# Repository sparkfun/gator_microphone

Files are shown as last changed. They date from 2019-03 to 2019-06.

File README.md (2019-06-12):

SparkFun gator:microphone - micro:bit Accessory Board 
=============================

SparkFun gator:microphone - micro:bit Accessory Board

[*SparkFun gator:microphone - micro:bit Accessory Board (SEN-15289)*](https://www.sparkfun.com/products/15289)  

An I<sup>2</sup>C sensor for detecting sound with an electret microphone. The sensor measures the actual audio, amplitude envelope, and sound indication with an ADC (ADS1015).

Instead of using pin connections or requiring soldering, this product provides connection pads for a more kid freindly experience with alligator clips. The design intention of this product is to be used with the [gato:bit (v2)](https://www.sparkfun.com/products/15162), and the [micro:bit development board](https://www.sparkfun.com/products/14208).

Repository Contents
-------------------

* **/Hardware** - Eagle design files (.brd, .sch)
* **/Production** - Production panel files (.brd)

Documentation
--------------

* **[Hookup Guide](https://learn.sparkfun.com/tutorials/sparkfun-gatormicrophone-hookup-guide)** - Basic hookup guide for the gator:microphone.
* **[gator:microphone PXT Package](https://github.com/sparkfun/pxt-gator-microphone)** - PXT- package for the MakeCode gator:microphone extension.

License Information
-------------------

This product is _**open source**_! 

Please review the LICENSE.md file for license information. 

If you have any questions or concerns on licensing, please visit the [SparkFun Forum](https://forum.sparkfun.com/index.php) and post a topic. For more general questions related to our gator boards, please visit this section of the forum: [Gator Products](https://forum.sparkfun.com/viewforum.php?f=162).

Distributed as-is; no warranty is given.

- Your friends at SparkFun.

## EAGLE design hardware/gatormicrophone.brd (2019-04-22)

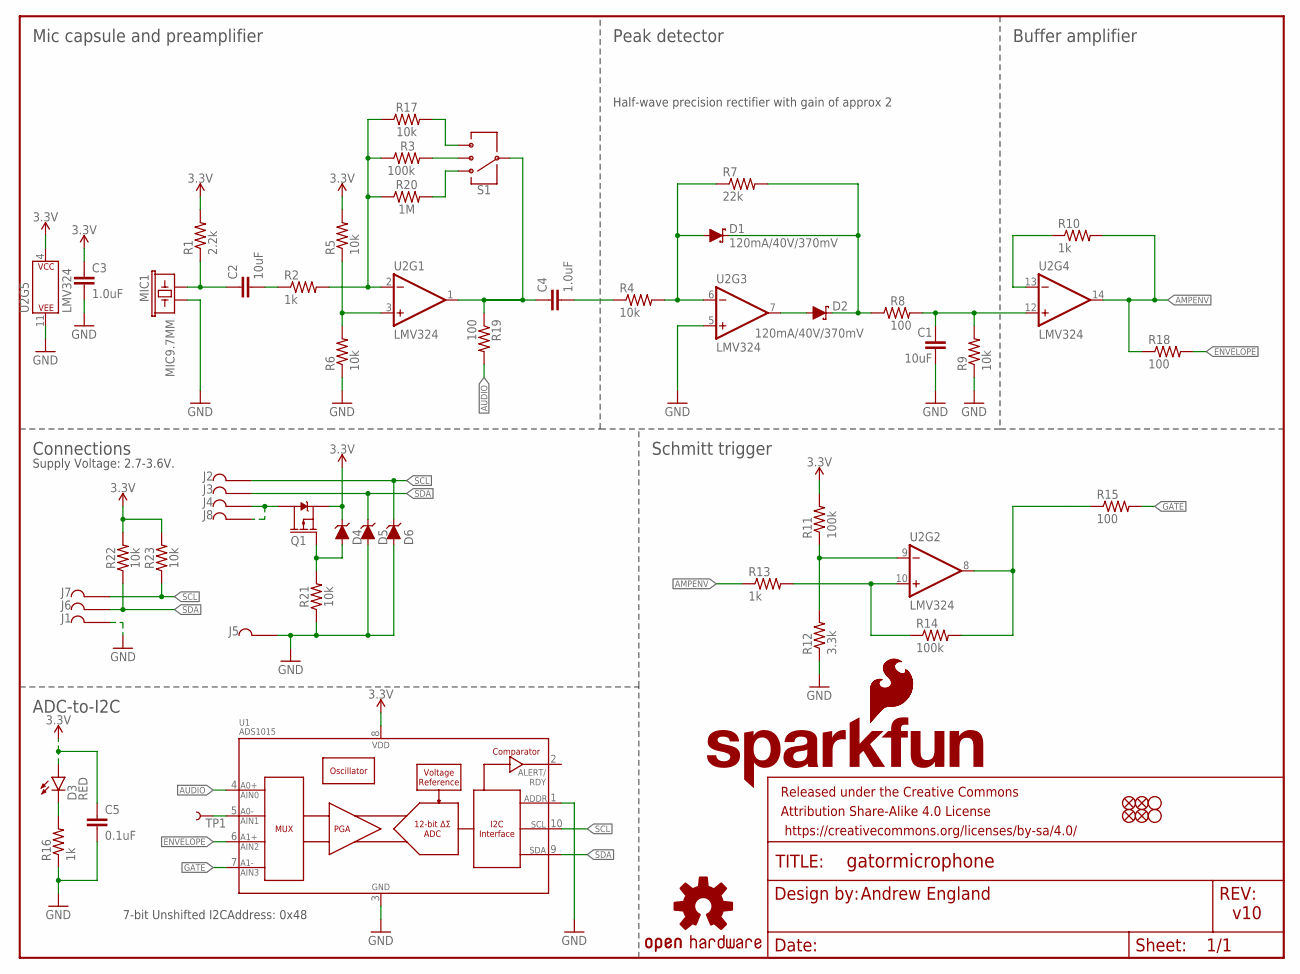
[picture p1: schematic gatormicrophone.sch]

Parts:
C1, C2: 10uF; 1206@1
C3, C4: 1.0uF; 0603
C5: 0.1uF; 0603
D1, D2: 120mA/40V/370mV; SOD-523
D3: RED; LED-0603
D4, D5, D6: 3.6V; SOD-323
FID1, FID2, FID3, FID4: FIDUCIAL1X2; FIDUCIAL-1X2
FRAME1: FRAME-LETTER; CREATIVE_COMMONS
H1, H2: STAND-OFFTIGHT; STAND-OFF-TIGHT
J1, J2, J3, J4, J5, J6, J7, J8: GATORGATOR_MINI; GATOR_MINI
LOGO1: OSHW-LOGOS; OSHW-LOGO-S
LOGO2: SFE_LOGO_NAME_FLAME.2_INCH; SFE_LOGO_NAME_FLAME_.2
LOGO3: SFE_LOGO_FLAME.2_INCH; SFE_LOGO_FLAME_.2
MIC1: MIC9.7MM; MIC-9.7MM
Q1: 2.5A/30V/105mΩ; SOT23-3
R1: 2.2k; 0603
R2, R10, R13, R16: 1k; 0603
R3, R11, R14: 100k; 0603
R4, R5, R6, R9, R17, R21, R22, R23: 10k; 0603
R7: 22k; 0603
R8, R15, R18, R19: 100; 0603
R12: 3.3k; 0603
R20: 1M; 0603
S1: SWITCH-SP3T-SMD; SWITCH_SP3T_SMD
TP1: TEST-POINT3; PAD.03X.03
U1: ADS1015; MSOP10
U2: LMV324; SO14

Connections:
3.3V: C3.1, C5.1, D3.A, D4.C, Q1.2 (S), R1.2, R5.2, R11.2, R22.2, R23.2, U1.8 (VDD), U2.4 (P$V+)
AMPENV: R10.2, R13.1, R18.1, U2.14 (OUT)
AUDIO: R19.2, U1.4 (AIN0)
ENVELOPE: R18.2, U1.6 (AIN2)
GATE: R15.2, U1.7 (AIN3)
GND: C1.2, C3.2, C5.2, D5.A, D6.A, J1.P$2, J5.P$2, MIC1.2, R6.1, R9.1, R12.1, R16.1, R21.1, U1.1 (ADDR), U1.3 (VSS), U2.5 (+IN), U2.11 (P$V-)
N$: C4.1, R19.1, S1.3, U2.1 (OUT)
unnamed: C2.1, MIC1.1, R1.1
unnamed: R5.1, R6.2, U2.3 (+IN)
unnamed: D3.C, R16.2
unnamed: R2.2, R3.1, R17.1, R20.1, U2.2 (-IN)
unnamed: C2.2, R2.1
unnamed: C4.2, R4.1
unnamed: D1.A, R4.2, R7.1, U2.6 (-IN)
unnamed: D2.A, U2.7 (OUT)
unnamed: D1.C, D2.C, R7.2, R8.1
unnamed: C1.1, R8.2, R9.2, U2.12 (+IN)
unnamed: R10.1, U2.13 (-IN)
unnamed: TP1.P$1, U1.5 (AIN1)
unnamed: R17.2, S1.4
unnamed: R3.2, S1.2
unnamed: R11.1, R12.2, U2.9 (-IN)
unnamed: R13.2, R14.1, U2.10 (+IN)
unnamed: R14.2, R15.1, U2.8 (OUT)
unnamed: R20.2, S1.1
unnamed: J4.P$2, J8.P$2, Q1.3 (D)
unnamed: D4.A, Q1.1 (G), R21.2
SCL: D6.C, J2.P$2, J7.P$2, R23.1, U1.10 (SCL)
SDA: D5.C, J3.P$2, J6.P$2, R22.1, U1.9 (SDA)

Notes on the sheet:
Andrew England
v10
Mic capsule and preamplifier
Peak detector
Buffer amplifier
Connections
Schmitt trigger
Half-wave precision rectifier with gain of approx 2
Supply Voltage: 2.7-3.6V.
ADC-to-I2C
7-bit Unshifted I2CAddress: 0x48

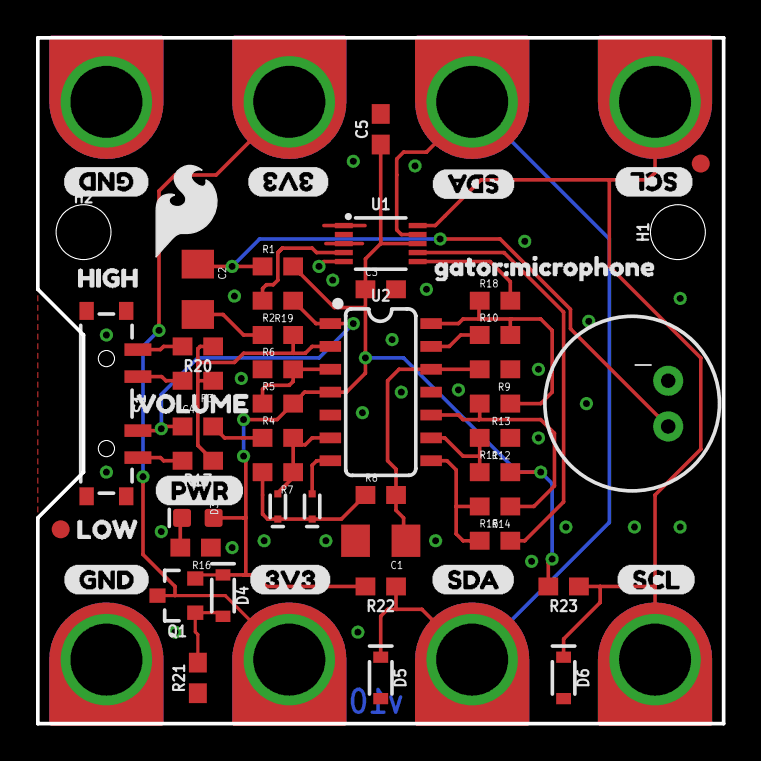
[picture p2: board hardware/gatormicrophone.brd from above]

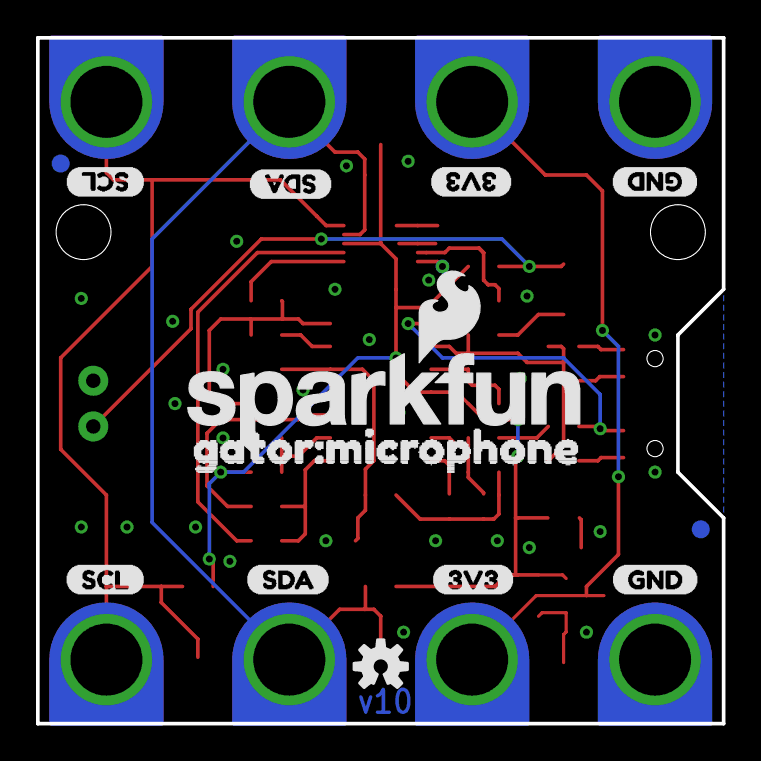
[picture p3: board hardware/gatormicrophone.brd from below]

Board: 2 copper layers, 38.1 x 38.1 mm, 81 parts (14 on the bottom side), 29 nets.

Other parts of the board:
U$1, U$7, U$11, U$18: 3V31
U$2, U$9, U$13, U$20: SCL1
U$3, U$8, U$12, U$19: SDA2
U$4: PWR0
U$5, U$6, U$10, U$17: GND0
U$14: GATOR#MICROPHONE1
U$15: LOW1
U$16: VOLUME2
U$21: HIGH0
U$22: ORDERING_INSTRUCTIONS
U$24: GATOR#MICROPHONE0

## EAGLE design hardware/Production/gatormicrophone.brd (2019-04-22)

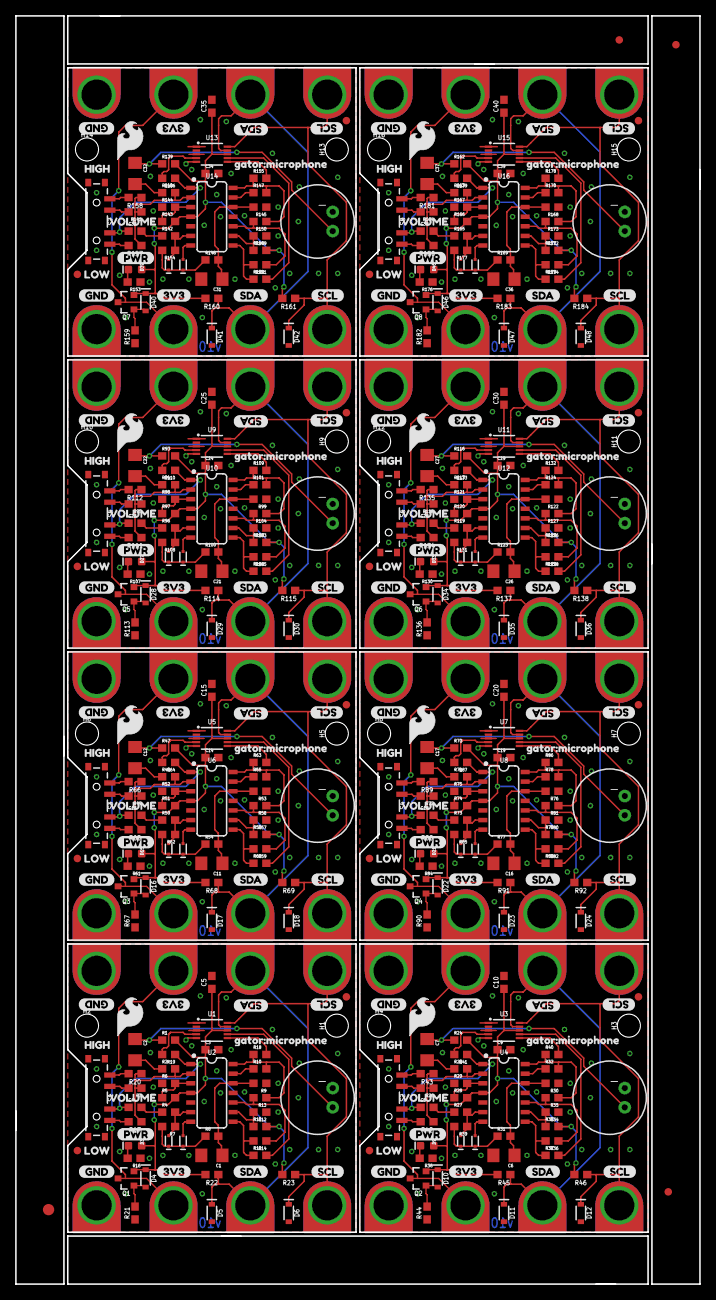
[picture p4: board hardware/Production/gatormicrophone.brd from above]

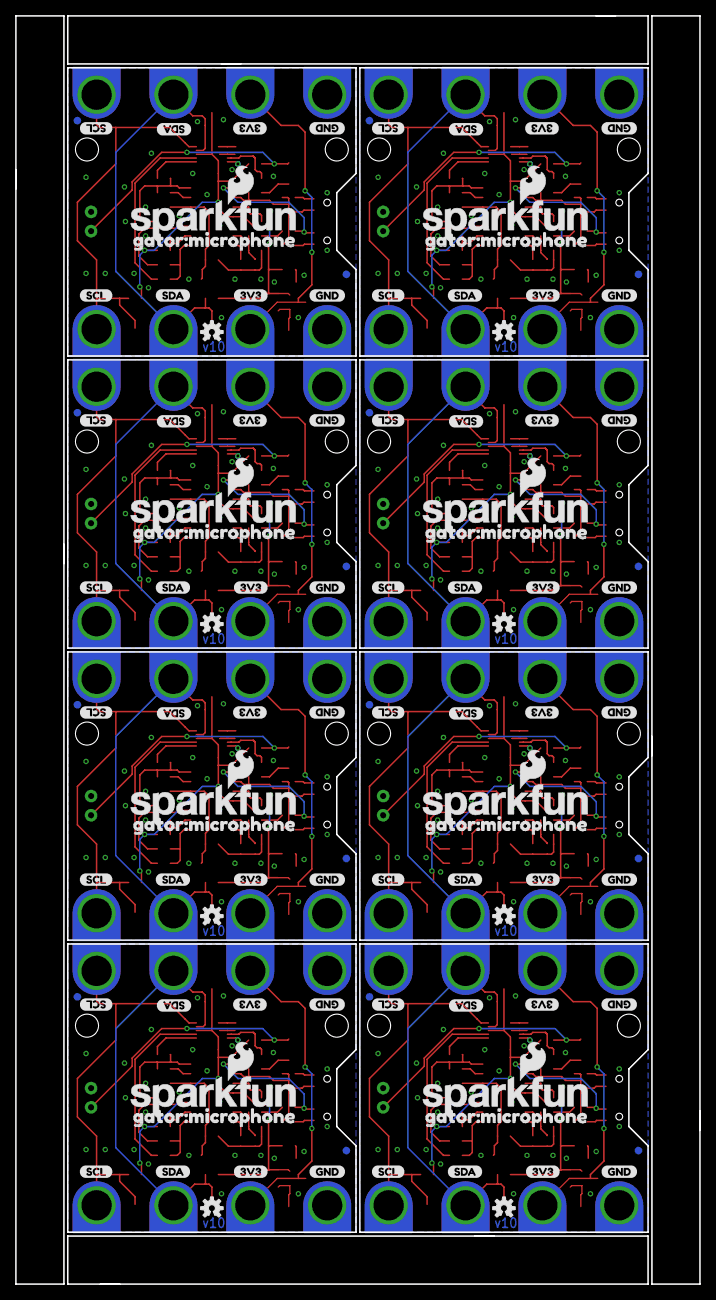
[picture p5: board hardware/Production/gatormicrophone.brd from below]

Board: 2 copper layers, 90.4 x 167.6 mm, 639 parts (112 on the bottom side), 232 nets.

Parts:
C1, C2, C6, C7, C11, C12, C16, C17, C21, C22, C26, C27, C31, C32, C36, C37: 10uF; 1206@1
C3, C4, C8, C9, C13, C14, C18, C19, C23, C24, C28, C29, C33, C34, C38, C39: 1.0uF; 0603
C5, C10, C15, C20, C25, C30, C35, C40: 0.1uF; 0603
D1, D2, D7, D8, D13, D14, D19, D20, D25, D26, D31, D32, D37, D38, D43, D44: 120mA/40V/370mV; SOD-523
D3, D9, D15, D21, D27, D33, D39, D45: RED; LED-0603
D4, D5, D6, D10, D11, D12, D16, D17, D18, D22, D23, D24, D28, D29, D30, D34, D35, D36, D40, D41, D42, D46, D47, D48: 3.6V; SOD-323
E$3: FIDUCIAL-1.5X3
E$5, E$7, E$8: FIDUCIAL-1X2
FID1, FID2, FID3, FID4, FID5, FID6, FID7, FID8, FID9, FID10, FID11, FID12, FID13, FID14, FID15, FID16, FID17, FID18, FID19, FID20, FID21, FID22, FID23, FID24, FID25, FID26, FID27, FID28, FID29, FID30, FID31, FID32: FIDUCIAL1X2; FIDUCIAL-1X2
FRAME1, FRAME2: FRAME-LETTER; CREATIVE_COMMONS
H1, H2, H3, H4, H5, H6, H7, H8, H9, H10, H11, H12, H13, H14, H15, H16: STAND-OFFTIGHT; STAND-OFF-TIGHT
J1, J2, J3, J4, J5, J6, J7, J8, J9, J10, J11, J12, J13, J14, J15, J16, J17, J18, J19, J20, J21, J22, J23, J24, J25, J26, J27, J28, J29, J30, J31, J32, J33, J34, J35, J36, J37, J38, J39, J40, J41, J42, J43, J44, J45, J46, J47, J48, J49, J50, J51, J52, J53, J54, J55, J56, J57, J58, J59, J60, J61, J62, J63, J64: GATORGATOR_MINI; GATOR_MINI
LOGO1, LOGO4, LOGO7, LOGO10, LOGO13, LOGO16, LOGO19, LOGO22: OSHW-LOGOS; OSHW-LOGO-S
LOGO2, LOGO5, LOGO8, LOGO11, LOGO14, LOGO17, LOGO20, LOGO23: SFE_LOGO_NAME_FLAME.2_INCH; SFE_LOGO_NAME_FLAME_.2
LOGO3, LOGO6, LOGO9, LOGO12, LOGO15, LOGO18, LOGO21, LOGO24: SFE_LOGO_FLAME.2_INCH; SFE_LOGO_FLAME_.2
MIC1, MIC2, MIC3, MIC4, MIC5, MIC6, MIC7, MIC8: MIC9.7MM; MIC-9.7MM
Q1, Q2, Q3, Q4, Q5, Q6, Q7, Q8: 2.5A/30V/105mΩ; SOT23-3
R1, R24, R47, R70, R93, R116, R139, R162: 2.2k; 0603
R2, R10, R13, R16, R25, R32, R35, R38, R48, R55, R58, R61, R71, R78, R81, R84, R94, R101, R104, R107, R117, R124, R127, R130, R140, R147, R150, R153, R163, R170, R173, R176: 1k; 0603
R3, R11, R14, R26, R33, R36, R49, R56, R59, R72, R79, R82, R95, R102, R105, R118, R125, R128, R141, R148, R151, R164, R171, R174: 100k; 0603
R4, R5, R6, R9, R17, R21, R22, R23, R27, R28, R29, R30, R42, R44, R45, R46, R50, R51, R52, R53, R65, R67, R68, R69, R73, R74, R75, R76, R88, R90, R91, R92, R96, R97, R98, R99, R111, R113, R114, R115, R119, R120, R121, R122, R134, R136, R137, R138, R142, R143, R144, R145, R157, R159, R160, R161, R165, R166, R167, R168, R180, R182, R183, R184: 10k; 0603
R7, R39, R62, R85, R108, R131, R154, R177: 22k; 0603
R8, R15, R18, R19, R31, R37, R40, R41, R54, R60, R63, R64, R77, R83, R86, R87, R100, R106, R109, R110, R123, R129, R132, R133, R146, R152, R155, R156, R169, R175, R178, R179: 100; 0603
R12, R34, R57, R80, R103, R126, R149, R172: 3.3k; 0603
R20, R43, R66, R89, R112, R135, R158, R181: 1M; 0603
S1, S2, S3, S4, S5, S6, S7, S8: SWITCH_SP3T_SMD
TP1, TP2, TP3, TP4, TP5, TP6, TP7, TP8: TEST-POINT3; PAD.03X.03
U1, U3, U5, U7, U9, U11, U13, U15: ADS1015; MSOP10
U2, U4, U6, U8, U10, U12, U14, U16: LMV324; SO14
U$1, U$7, U$11, U$18, U$23, U$27, U$34, U$40, U$46, U$49, U$56, U$62, U$68, U$71, U$78, U$84, U$90, U$93, U$100, U$106, U$112, U$115, U$122, U$128, U$134, U$137, U$144, U$150, U$156, U$159, U$166, U$172: 3V31
U$2, U$9, U$13, U$20, U$28, U$32, U$36, U$42, U$50, U$54, U$58, U$64, U$72, U$76, U$80, U$86, U$94, U$98, U$102, U$108, U$116, U$120, U$124, U$130, U$138, U$142, U$146, U$152, U$160, U$164, U$168, U$174: SCL1
U$3, U$8, U$12, U$19, U$29, U$31, U$35, U$41, U$51, U$53, U$57, U$63, U$73, U$75, U$79, U$85, U$95, U$97, U$101, U$107, U$117, U$119, U$123, U$129, U$139, U$141, U$145, U$151, U$161, U$163, U$167, U$173: SDA2
U$4, U$30, U$52, U$74, U$96, U$118, U$140, U$162: PWR0
U$5, U$6, U$10, U$17, U$25, U$26, U$33, U$39, U$47, U$48, U$55, U$61, U$69, U$70, U$77, U$83, U$91, U$92, U$99, U$105, U$113, U$114, U$121, U$127, U$135, U$136, U$143, U$149, U$157, U$158, U$165, U$171: GND0
U$14, U$45, U$67, U$89, U$111, U$133, U$155, U$177: GATOR#MICROPHONE1
U$15, U$37, U$59, U$81, U$103, U$125, U$147, U$169: LOW1
U$16, U$38, U$60, U$82, U$104, U$126, U$148, U$170: VOLUME2
U$21, U$43, U$65, U$87, U$109, U$131, U$153, U$175: HIGH0
U$22: ORDERING_INSTRUCTIONS
U$24, U$44, U$66, U$88, U$110, U$132, U$154, U$176: GATOR#MICROPHONE0

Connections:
3.3V: C3.1, C5.1, D3.A, D4.C, Q1.2, R1.2, R5.2, R11.2, R22.2, R23.2, U1.8, U2.4
3.3V1: C9.1, C10.1, D9.A, D10.C, Q2.2, R24.2, R28.2, R33.2, R45.2, R46.2, U3.8, U4.4
3.3V2: C14.1, C15.1, D15.A, D16.C, Q3.2, R47.2, R51.2, R56.2, R68.2, R69.2, U5.8, U6.4
3.3V3: C19.1, C20.1, D21.A, D22.C, Q4.2, R70.2, R74.2, R79.2, R91.2, R92.2, U7.8, U8.4
3.3V4: C24.1, C25.1, D27.A, D28.C, Q5.2, R93.2, R97.2, R102.2, R114.2, R115.2, U9.8, U10.4
3.3V5: C29.1, C30.1, D33.A, D34.C, Q6.2, R116.2, R120.2, R125.2, R137.2, R138.2, U11.8, U12.4
3.3V6: C34.1, C35.1, D39.A, D40.C, Q7.2, R139.2, R143.2, R148.2, R160.2, R161.2, U13.8, U14.4
3.3V7: C39.1, C40.1, D45.A, D46.C, Q8.2, R162.2, R166.2, R171.2, R183.2, R184.2, U15.8, U16.4
AMPENV: R10.2, R13.1, R18.1, U2.14
AMPENV1: R32.2, R35.1, R40.1, U4.14
AMPENV2: R55.2, R58.1, R63.1, U6.14
AMPENV3: R78.2, R81.1, R86.1, U8.14
AMPENV4: R101.2, R104.1, R109.1, U10.14
AMPENV5: R124.2, R127.1, R132.1, U12.14
AMPENV6: R147.2, R150.1, R155.1, U14.14
AMPENV7: R170.2, R173.1, R178.1, U16.14
AUDIO: R19.2, U1.4
AUDIO1: R41.2, U3.4
AUDIO2: R64.2, U5.4
AUDIO3: R87.2, U7.4
AUDIO4: R110.2, U9.4
AUDIO5: R133.2, U11.4
AUDIO6: R156.2, U13.4
AUDIO7: R179.2, U15.4
ENVELOPE: R18.2, U1.6
ENVELOPE1: R40.2, U3.6
ENVELOPE2: R63.2, U5.6
ENVELOPE3: R86.2, U7.6
ENVELOPE4: R109.2, U9.6
ENVELOPE5: R132.2, U11.6
ENVELOPE6: R155.2, U13.6
ENVELOPE7: R178.2, U15.6
GATE: R15.2, U1.7
GATE1: R37.2, U3.7
GATE2: R60.2, U5.7
GATE3: R83.2, U7.7
GATE4: R106.2, U9.7
GATE5: R129.2, U11.7
GATE6: R152.2, U13.7
GATE7: R175.2, U15.7
GND: C1.2, C3.2, C5.2, D5.A, D6.A, J1.P$2, J5.P$2, MIC1.2, R6.1, R9.1, R12.1, R16.1, R21.1, U1.1, U1.3, U2.5, U2.11
GND1: C6.2, C9.2, C10.2, D11.A, D12.A, J12.P$2, J13.P$2, MIC2.2, R29.1, R30.1, R34.1, R38.1, R44.1, U3.1, U3.3, U4.5, U4.11
GND2: C11.2, C14.2, C15.2, D17.A, D18.A, J20.P$2, J21.P$2, MIC3.2, R52.1, R53.1, R57.1, R61.1, R67.1, U5.1, U5.3, U6.5, U6.11
GND3: C16.2, C19.2, C20.2, D23.A, D24.A, J28.P$2, J29.P$2, MIC4.2, R75.1, R76.1, R80.1, R84.1, R90.1, U7.1, U7.3, U8.5, U8.11
GND4: C21.2, C24.2, C25.2, D29.A, D30.A, J36.P$2, J37.P$2, MIC5.2, R98.1, R99.1, R103.1, R107.1, R113.1, U9.1, U9.3, U10.5, U10.11
GND5: C26.2, C29.2, C30.2, D35.A, D36.A, J44.P$2, J45.P$2, MIC6.2, R121.1, R122.1, R126.1, R130.1, R136.1, U11.1, U11.3, U12.5, U12.11
GND6: C31.2, C34.2, C35.2, D41.A, D42.A, J52.P$2, J53.P$2, MIC7.2, R144.1, R145.1, R149.1, R153.1, R159.1, U13.1, U13.3, U14.5, U14.11
GND7: C36.2, C39.2, C40.2, D47.A, D48.A, J60.P$2, J61.P$2, MIC8.2, R167.1, R168.1, R172.1, R176.1, R182.1, U15.1, U15.3, U16.5, U16.11
N$: C4.1, R19.1, S1.3, U2.1
unnamed: C2.1, MIC1.1, R1.1
unnamed: R5.1, R6.2, U2.3
unnamed: D3.C, R16.2
unnamed: R2.2, R3.1, R17.1, R20.1, U2.2
unnamed: C2.2, R2.1
unnamed: C4.2, R4.1
unnamed: D1.A, R4.2, R7.1, U2.6
unnamed: D2.A, U2.7
unnamed: D1.C, D2.C, R7.2, R8.1
unnamed: C1.1, R8.2, R9.2, U2.12
unnamed: R10.1, U2.13
unnamed: TP1.P$1, U1.5
unnamed: R17.2, S1.4
unnamed: R3.2, S1.2
unnamed: R11.1, R12.2, U2.9
unnamed: R13.2, R14.1, U2.10
unnamed: R14.2, R15.1, U2.8
unnamed: R20.2, S1.1
unnamed: J4.P$2, J8.P$2, Q1.3
unnamed: D4.A, Q1.1, R21.2
unnamed: C7.1, MIC2.1, R24.1
unnamed: R28.1, R29.2, U4.3
unnamed: R25.2, R26.1, R42.1, R43.1, U4.2
unnamed: C7.2, R25.1
unnamed: C8.2, R27.1
unnamed: D7.A, R27.2, R39.1, U4.6
unnamed: D8.A, U4.7
unnamed: D7.C, D8.C, R31.1, R39.2
unnamed: C6.1, R30.2, R31.2, U4.12
unnamed: R32.1, U4.13
unnamed: R33.1, R34.2, U4.9
unnamed: R35.2, R36.1, U4.10
unnamed: R36.2, R37.1, U4.8
unnamed: D9.C, R38.2
unnamed: C8.1, R41.1, S2.3, U4.1
unnamed: R42.2, S2.4
unnamed: R26.2, S2.2
unnamed: R43.2, S2.1
unnamed: J11.P$2, J16.P$2, Q2.3
unnamed: D10.A, Q2.1, R44.2
unnamed: TP2.P$1, U3.5
unnamed: C12.1, MIC3.1, R47.1
unnamed: R51.1, R52.2, U6.3
unnamed: R48.2, R49.1, R65.1, R66.1, U6.2
unnamed: C12.2, R48.1
unnamed: C13.2, R50.1
unnamed: D13.A, R50.2, R62.1, U6.6
unnamed: D14.A, U6.7
unnamed: D13.C, D14.C, R54.1, R62.2
unnamed: C11.1, R53.2, R54.2, U6.12
unnamed: R55.1, U6.13
unnamed: R56.1, R57.2, U6.9
unnamed: R58.2, R59.1, U6.10
unnamed: R59.2, R60.1, U6.8
unnamed: D15.C, R61.2
unnamed: C13.1, R64.1, S3.3, U6.1
unnamed: R65.2, S3.4
unnamed: R49.2, S3.2
unnamed: R66.2, S3.1
unnamed: J19.P$2, J24.P$2, Q3.3
unnamed: D16.A, Q3.1, R67.2
unnamed: TP3.P$1, U5.5
unnamed: C17.1, MIC4.1, R70.1
unnamed: R74.1, R75.2, U8.3
unnamed: R71.2, R72.1, R88.1, R89.1, U8.2
unnamed: C17.2, R71.1
unnamed: C18.2, R73.1
unnamed: D19.A, R73.2, R85.1, U8.6
unnamed: D20.A, U8.7
unnamed: D19.C, D20.C, R77.1, R85.2
unnamed: C16.1, R76.2, R77.2, U8.12
unnamed: R78.1, U8.13
unnamed: R79.1, R80.2, U8.9
unnamed: R81.2, R82.1, U8.10
unnamed: R82.2, R83.1, U8.8
unnamed: D21.C, R84.2
unnamed: C18.1, R87.1, S4.3, U8.1
unnamed: R88.2, S4.4
unnamed: R72.2, S4.2
unnamed: R89.2, S4.1
unnamed: J27.P$2, J32.P$2, Q4.3
unnamed: D22.A, Q4.1, R90.2
unnamed: TP4.P$1, U7.5
unnamed: C22.1, MIC5.1, R93.1
unnamed: R97.1, R98.2, U10.3
unnamed: R94.2, R95.1, R111.1, R112.1, U10.2
unnamed: C22.2, R94.1
unnamed: C23.2, R96.1
unnamed: D25.A, R96.2, R108.1, U10.6
unnamed: D26.A, U10.7
unnamed: D25.C, D26.C, R100.1, R108.2
unnamed: C21.1, R99.2, R100.2, U10.12
unnamed: R101.1, U10.13
unnamed: R102.1, R103.2, U10.9
unnamed: R104.2, R105.1, U10.10
unnamed: R105.2, R106.1, U10.8
unnamed: D27.C, R107.2
unnamed: C23.1, R110.1, S5.3, U10.1
unnamed: R111.2, S5.4
unnamed: R95.2, S5.2
unnamed: R112.2, S5.1
unnamed: J35.P$2, J40.P$2, Q5.3
unnamed: D28.A, Q5.1, R113.2
unnamed: TP5.P$1, U9.5
unnamed: C27.1, MIC6.1, R116.1
unnamed: R120.1, R121.2, U12.3
unnamed: R117.2, R118.1, R134.1, R135.1, U12.2
unnamed: C27.2, R117.1
unnamed: C28.2, R119.1
unnamed: D31.A, R119.2, R131.1, U12.6
unnamed: D32.A, U12.7
unnamed: D31.C, D32.C, R123.1, R131.2
unnamed: C26.1, R122.2, R123.2, U12.12
unnamed: R124.1, U12.13
unnamed: R125.1, R126.2, U12.9
unnamed: R127.2, R128.1, U12.10
unnamed: R128.2, R129.1, U12.8
unnamed: D33.C, R130.2
unnamed: C28.1, R133.1, S6.3, U12.1
unnamed: R134.2, S6.4
unnamed: R118.2, S6.2
unnamed: R135.2, S6.1
unnamed: J43.P$2, J48.P$2, Q6.3
unnamed: D34.A, Q6.1, R136.2
unnamed: TP6.P$1, U11.5
unnamed: C32.1, MIC7.1, R139.1
unnamed: R143.1, R144.2, U14.3
unnamed: R140.2, R141.1, R157.1, R158.1, U14.2
unnamed: C32.2, R140.1
unnamed: C33.2, R142.1
unnamed: D37.A, R142.2, R154.1, U14.6
unnamed: D38.A, U14.7
unnamed: D37.C, D38.C, R146.1, R154.2
unnamed: C31.1, R145.2, R146.2, U14.12
unnamed: R147.1, U14.13
unnamed: R148.1, R149.2, U14.9
unnamed: R150.2, R151.1, U14.10
unnamed: R151.2, R152.1, U14.8
unnamed: D39.C, R153.2
unnamed: C33.1, R156.1, S7.3, U14.1
unnamed: R157.2, S7.4
unnamed: R141.2, S7.2
unnamed: R158.2, S7.1
unnamed: J51.P$2, J56.P$2, Q7.3
unnamed: D40.A, Q7.1, R159.2
unnamed: TP7.P$1, U13.5
unnamed: C37.1, MIC8.1, R162.1
unnamed: R166.1, R167.2, U16.3
unnamed: R163.2, R164.1, R180.1, R181.1, U16.2
unnamed: C37.2, R163.1
unnamed: C38.2, R165.1
unnamed: D43.A, R165.2, R177.1, U16.6
unnamed: D44.A, U16.7
unnamed: D43.C, D44.C, R169.1, R177.2
unnamed: C36.1, R168.2, R169.2, U16.12
unnamed: R170.1, U16.13
unnamed: R171.1, R172.2, U16.9
unnamed: R173.2, R174.1, U16.10
unnamed: R174.2, R175.1, U16.8
unnamed: D45.C, R176.2
unnamed: C38.1, R179.1, S8.3, U16.1
unnamed: R180.2, S8.4
unnamed: R164.2, S8.2
unnamed: R181.2, S8.1
unnamed: J59.P$2, J64.P$2, Q8.3
unnamed: D46.A, Q8.1, R182.2
unnamed: TP8.P$1, U15.5
SCL: D6.C, J2.P$2, J7.P$2, R23.1, U1.10
SCL1: D12.C, J9.P$2, J15.P$2, R46.1, U3.10
SCL2: D18.C, J17.P$2, J23.P$2, R69.1, U5.10
SCL3: D24.C, J25.P$2, J31.P$2, R92.1, U7.10
SCL4: D30.C, J33.P$2, J39.P$2, R115.1, U9.10
SCL5: D36.C, J41.P$2, J47.P$2, R138.1, U11.10
SCL6: D42.C, J49.P$2, J55.P$2, R161.1, U13.10
SCL7: D48.C, J57.P$2, J63.P$2, R184.1, U15.10
SDA: D5.C, J3.P$2, J6.P$2, R22.1, U1.9
SDA1: D11.C, J10.P$2, J14.P$2, R45.1, U3.9
SDA2: D17.C, J18.P$2, J22.P$2, R68.1, U5.9
SDA3: D23.C, J26.P$2, J30.P$2, R91.1, U7.9
SDA4: D29.C, J34.P$2, J38.P$2, R114.1, U9.9
SDA5: D35.C, J42.P$2, J46.P$2, R137.1, U11.9
SDA6: D41.C, J50.P$2, J54.P$2, R160.1, U13.9
SDA7: D47.C, J58.P$2, J62.P$2, R183.1, U15.9

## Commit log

2019-02-27 initial layout
    [11872_sound-detector-big.panel-v11.brd, Sound Detector analog.fzz, gain-calc.ods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]
2019-02-28 adding protection circuitry
    [sound-detector.brd, sound-detector.sch]
2019-03-18 post engineer run of checklist
    [sound-detector.brd, sound-detector.sch]
2019-03-18 adding to measures layer
    [sound-detector.brd]
2019-04-16 pre design review changes
    [sound-detector.GBL, sound-detector.GBO, sound-detector.GBS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]
2019-04-19 engineer run of checklist
    [gatormicrophone.brd, gatormicrophone.sch]
2019-04-22 adding panel
    [gatormicrophone.GBL, gatormicrophone.GBO, gatormicrophone.GBS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]
2019-06-12 Update to current product information
    Will need to update forum link and description
2019-06-14 cleaning repo
    [Sound Detector analog.fzz, gain-calc.ods]
2021-12-06 Remove old panel files
    [11872_sound-detector-big.panel-v11.brd, sound-detector-panel-v11.brd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]

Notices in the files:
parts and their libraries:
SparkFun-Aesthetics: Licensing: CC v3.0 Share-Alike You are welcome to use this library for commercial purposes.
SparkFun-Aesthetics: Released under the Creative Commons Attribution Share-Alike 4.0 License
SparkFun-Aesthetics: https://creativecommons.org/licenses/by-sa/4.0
